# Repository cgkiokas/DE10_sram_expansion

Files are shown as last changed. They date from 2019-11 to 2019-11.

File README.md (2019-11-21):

# DE10 SRAM expansion board 
An SRAM expansion board for terasic DE-10 Nano board, with additional flight controller sensors.
Developed to accompany a DE-10 Nano board as a drone flight controller, using [T-CREST's Patmos](https://github.com/t-crest/patmos) processor. 

## Features
* 1Mx32bit SRAM
* 2 x 6-axis IMUs
* Magnetometer
* Barometer
* FTDI for UART output
* 7 GPIO Pins
  
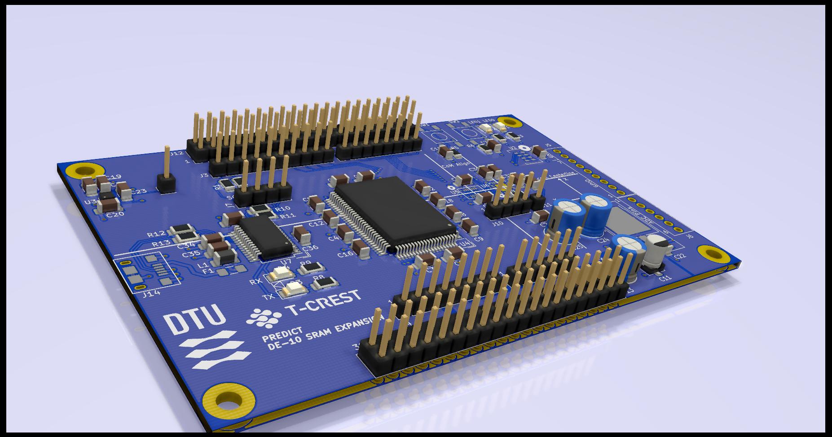
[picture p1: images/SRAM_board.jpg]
Title


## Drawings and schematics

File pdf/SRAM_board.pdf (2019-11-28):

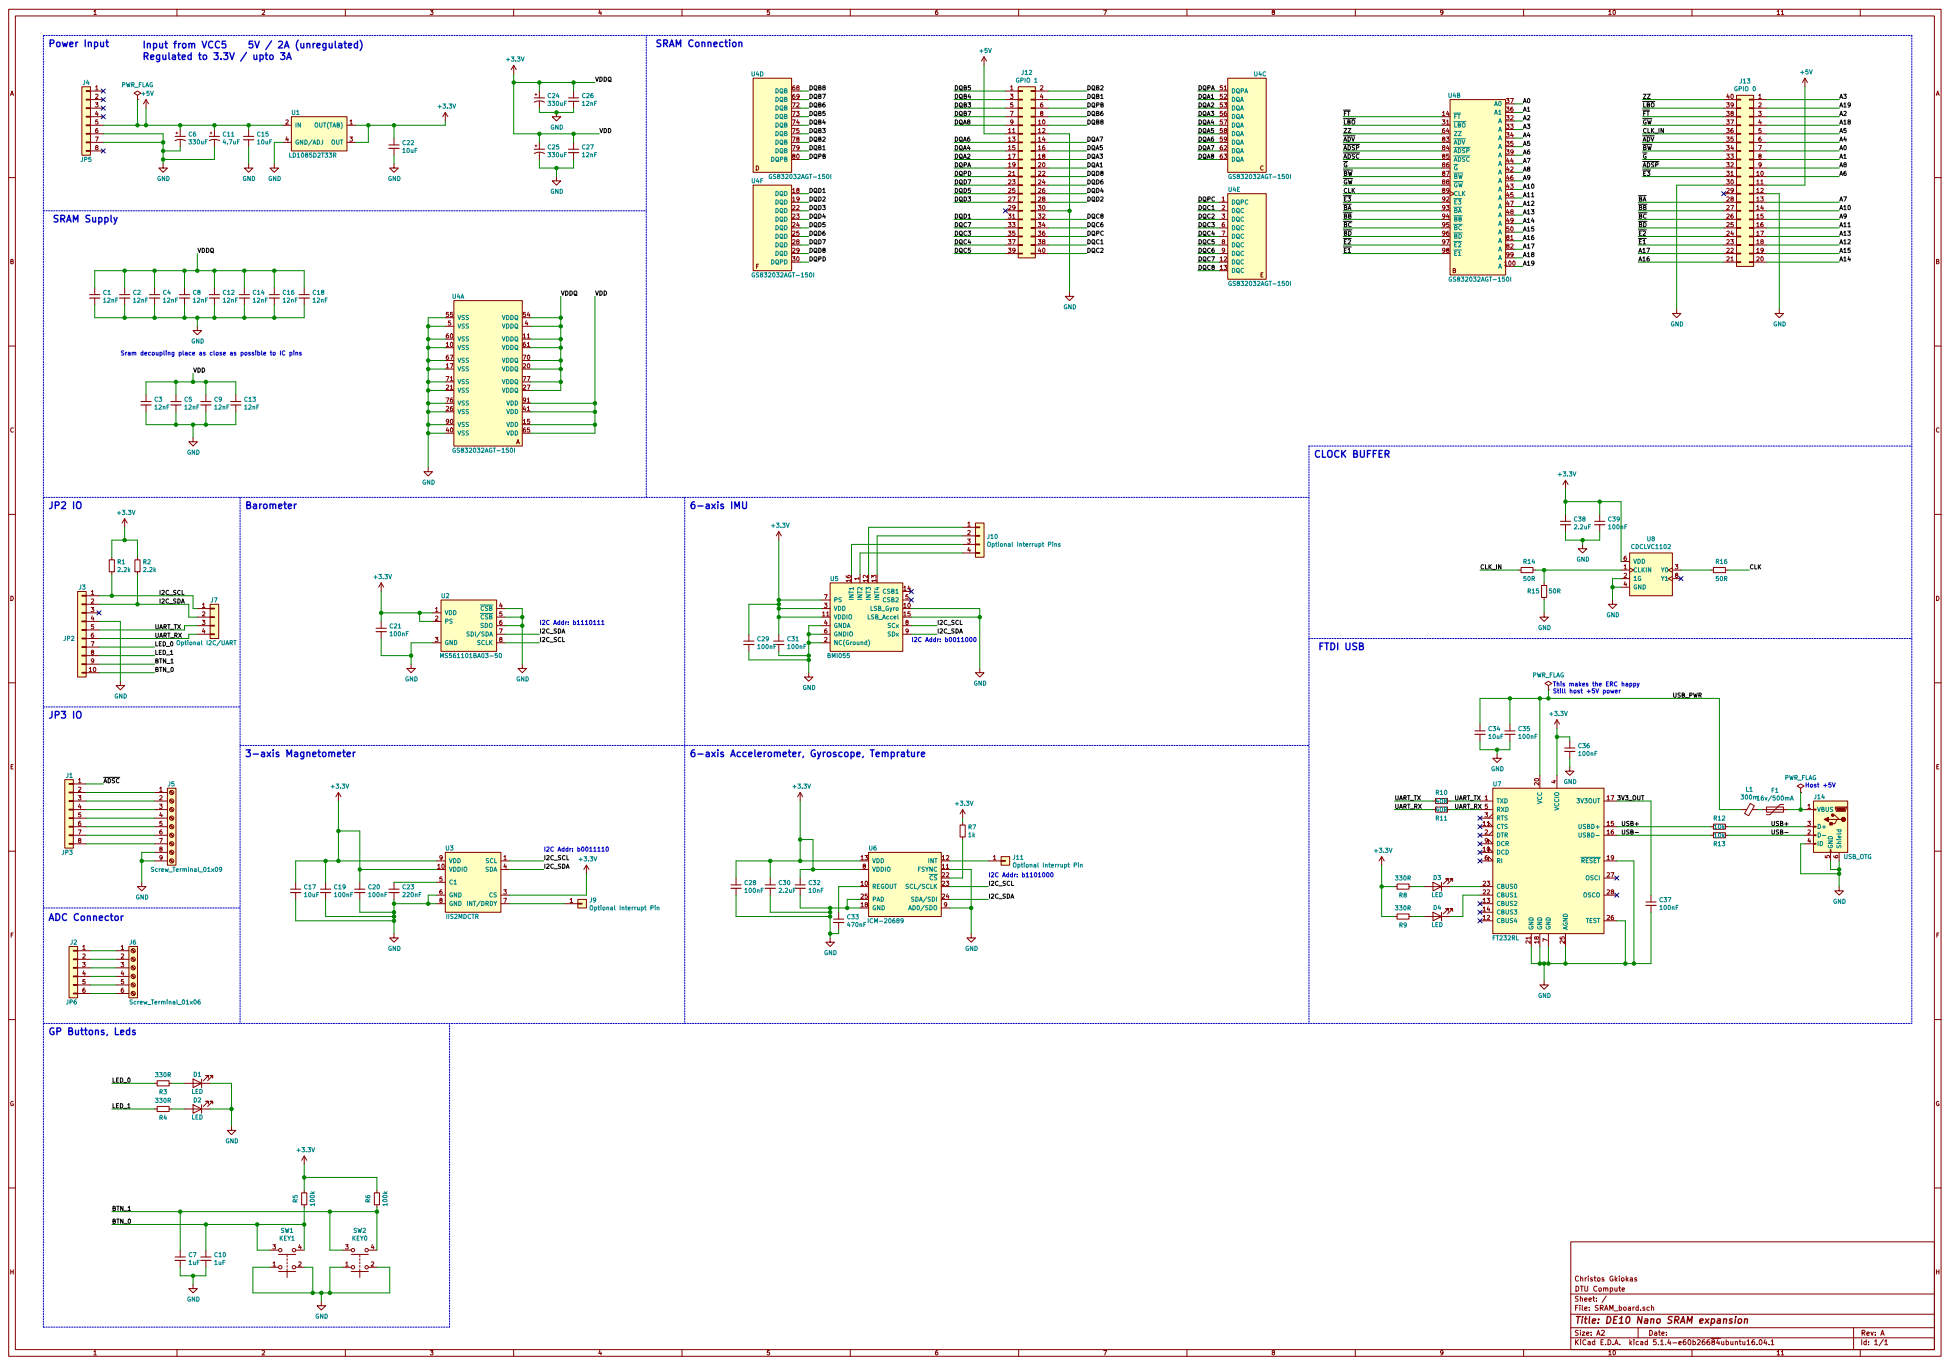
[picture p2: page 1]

JP2 IO +3.3V | LD1085D2T33R R6 100k +3.3V C10 Barometer +3.3V | 6-axis IMU | GND

Sram decoupling place as close as possible to IC pins

File: SRAM_board.sch Sheet: / DTU Compute Christos Gkiokas

Id: 1/1 Title: DE10 Nano SRAM expansion

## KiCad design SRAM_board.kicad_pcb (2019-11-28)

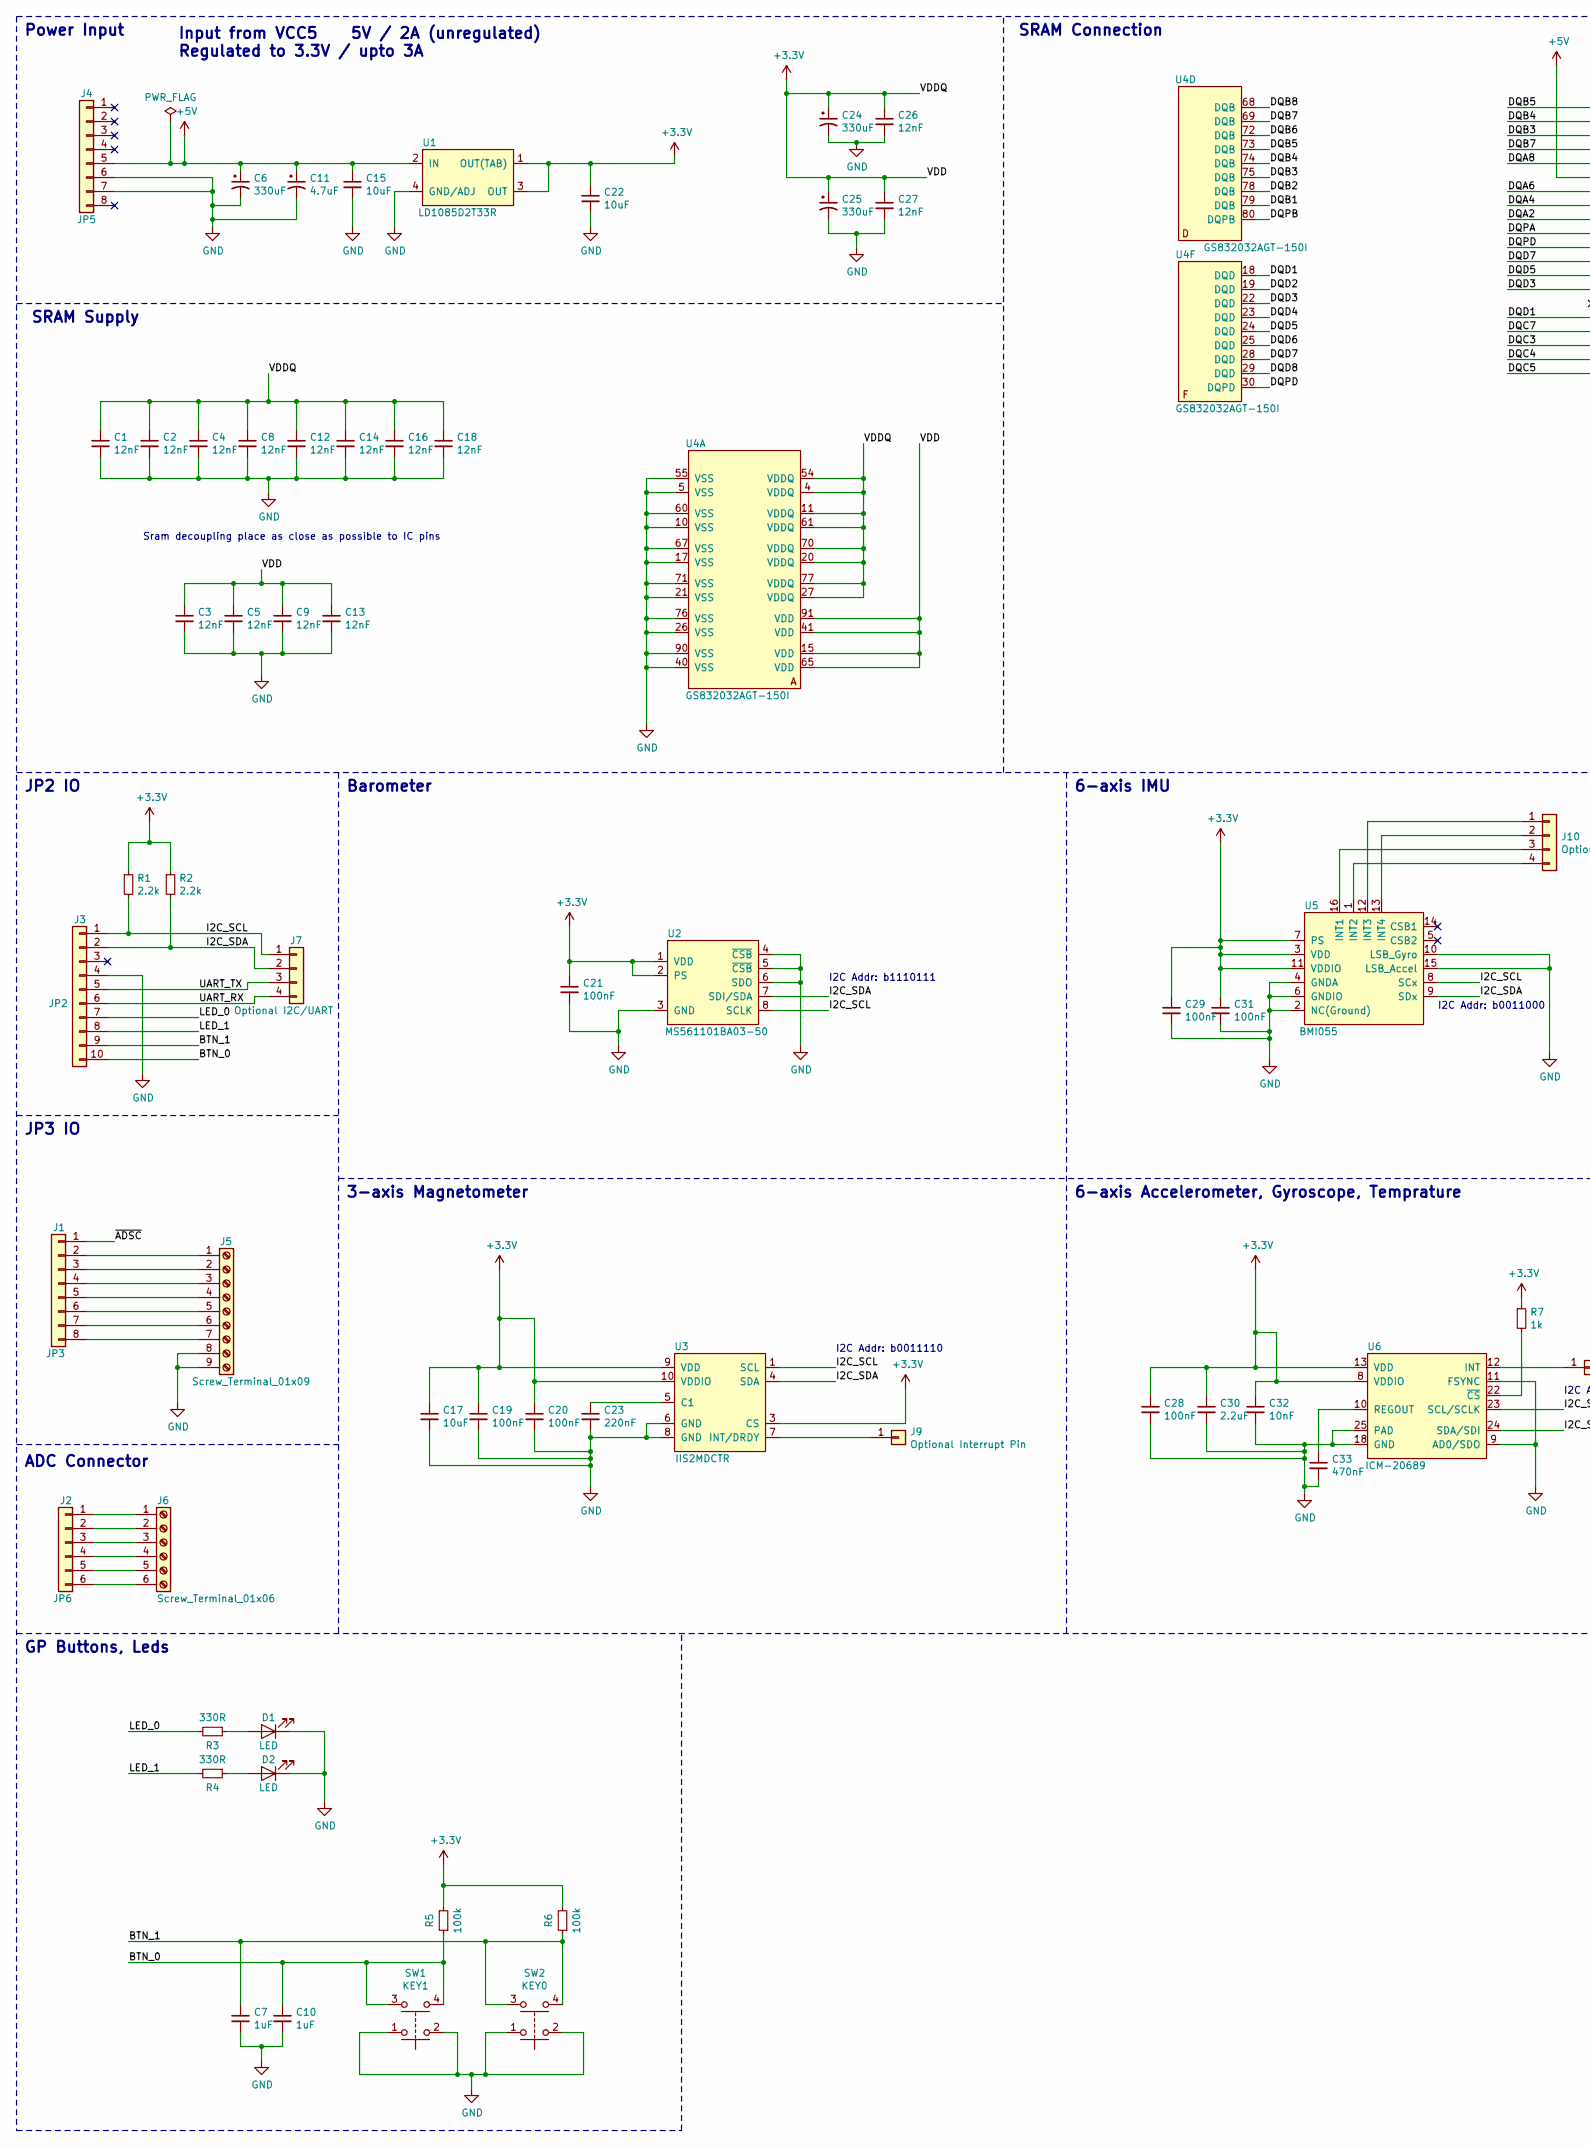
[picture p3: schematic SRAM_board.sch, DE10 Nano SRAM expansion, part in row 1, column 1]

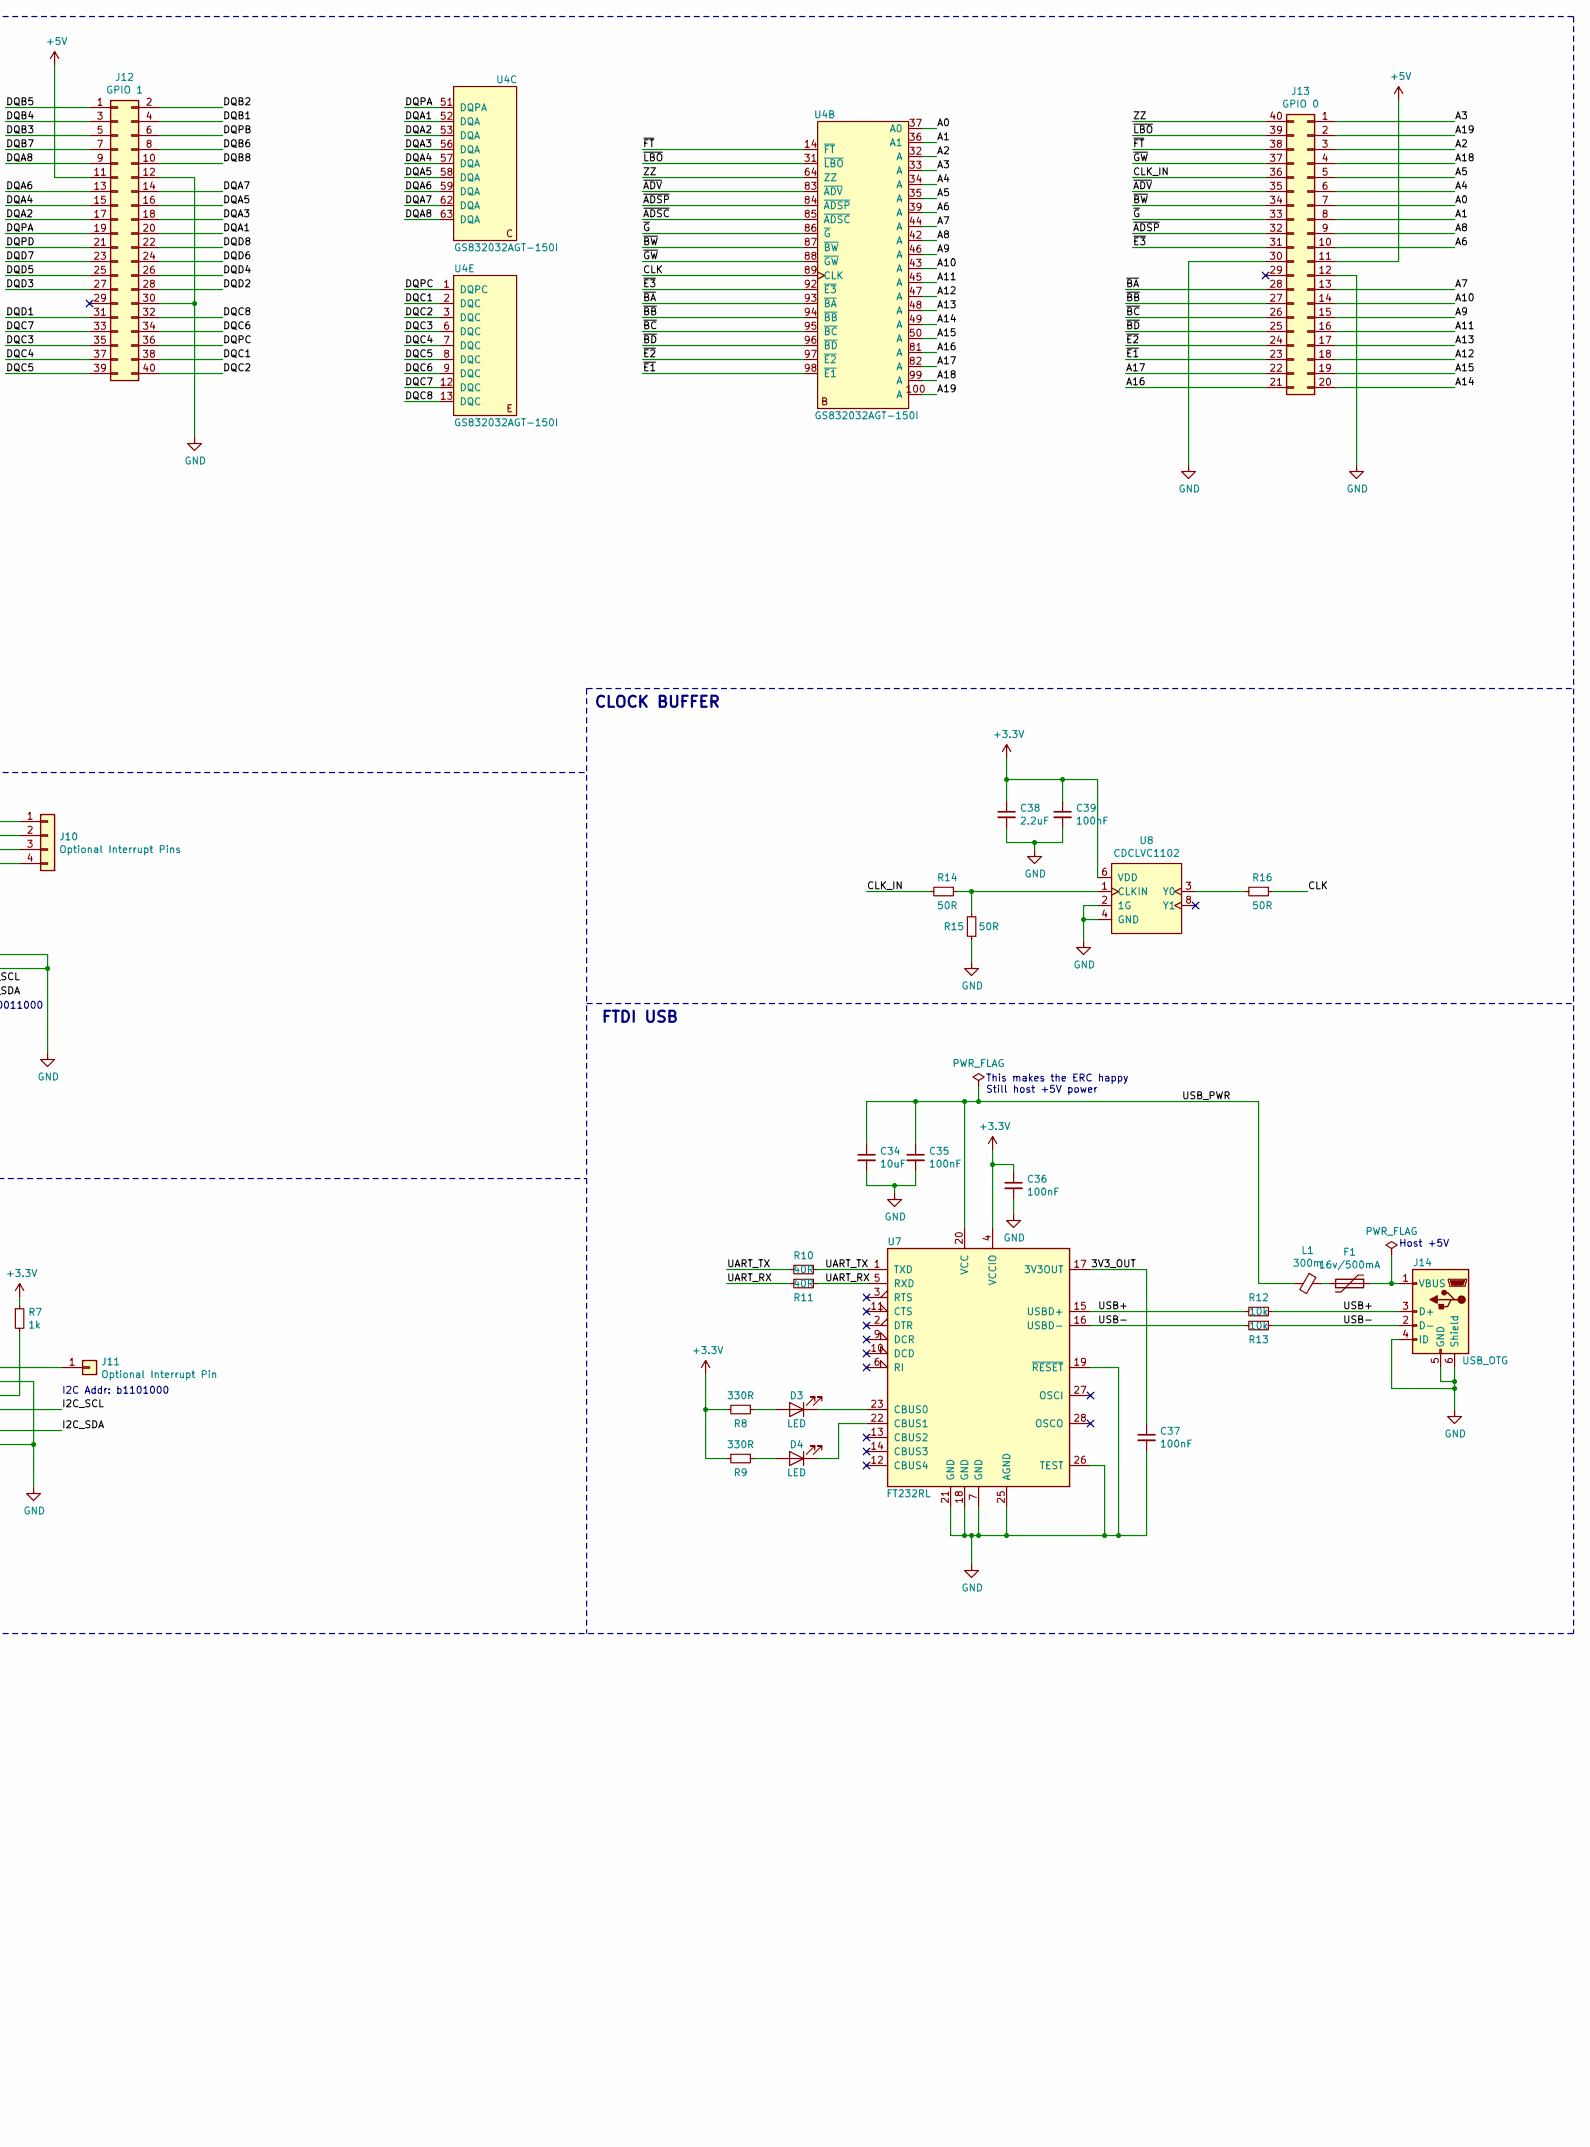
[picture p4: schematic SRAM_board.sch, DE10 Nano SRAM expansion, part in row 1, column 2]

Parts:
C1, C2, C3, C4, C5, C8, C9, C12, C13, C14, C16, C18, C26, C27: 12nF; C_1206_3216Metric_Pad1.42x1.75mm_HandSolder
C6, C24, C25: 330uF; CP_Radial_D6.3mm_P2.50mm
C7, C10: 1uF; C_1206_3216Metric_Pad1.42x1.75mm_HandSolder
C11: 4.7uF; CP_Elec_4x5.8
C15, C17, C22, C34: 10uF; C_1206_3216Metric_Pad1.42x1.75mm_HandSolder
C19, C20, C21, C28, C29, C31, C35, C36, C37, C39: 100nF; C_1206_3216Metric_Pad1.42x1.75mm_HandSolder
C23: 220nF; C_1206_3216Metric_Pad1.42x1.75mm_HandSolder
C30, C38: 2.2uF; C_1206_3216Metric_Pad1.42x1.75mm_HandSolder
C32: 10nF; C_1206_3216Metric_Pad1.42x1.75mm_HandSolder
C33: 470nF; C_1206_3216Metric_Pad1.42x1.75mm_HandSolder
D1, D2, D3, D4: LED; LED_1206_3216Metric_Pad1.42x1.75mm_HandSolder
F1: 16v/500mA; Fuse_1206_3216Metric_Pad1.42x1.75mm_HandSolder
J1: JP3; PinHeader_1x08_P2.54mm_Vertical
J2: JP6; PinHeader_1x06_P2.54mm_Vertical
J3: JP2; PinHeader_1x10_P2.54mm_Vertical
J4: JP5; PinHeader_1x08_P2.54mm_Vertical
J5: Screw_Terminal_01x09; Screw_Terminal_1x09_2.54'_pitch
J6: Screw_Terminal_01x06; Screw_Terminal_1x06_2.54'_pitch
J7: Optional I2C/UART; PinHeader_1x04_P2.54mm_Vertical
J9, J11: Optional Interrupt Pin; PinHeader_1x01_P2.54mm_Vertical
J10: Optional Interrupt Pins; PinHeader_1x04_P2.54mm_Vertical
J12: GPIO 1; PinHeader_2x20_P2.54mm_Vertical
J13: GPIO 0; PinHeader_2x20_P2.54mm_Vertical
J14: USB_OTG; FCI_10118193_0001LF
L1: 300m; L_1206_3216Metric_Pad1.42x1.75mm_HandSolder
R1, R2: 2.2k; R_1206_3216Metric_Pad1.42x1.75mm_HandSolder
R3, R4, R8, R9: 330R; R_1206_3216Metric_Pad1.42x1.75mm_HandSolder
R5, R6: 100k; R_1206_3216Metric_Pad1.42x1.75mm_HandSolder
R7: 1k; R_1206_3216Metric_Pad1.42x1.75mm_HandSolder
R10, R11: 40R; R_1206_3216Metric_Pad1.42x1.75mm_HandSolder
R12, R13: 10k; R_1206_3216Metric_Pad1.42x1.75mm_HandSolder
R14, R15, R16: 50R; R_1206_3216Metric_Pad1.42x1.75mm_HandSolder
SW1: KEY1; LL3301NF065QG
SW2: KEY0; LL3301NF065QG
U1: LD1085D2T33R
U2: MS561101BA03-50
U3: IIS2MDCTR; LGA-12_2x2mm_P0.5mm
U4: GS832032AGT-150I; PQFP-100_14x20mm_P0.65mm
U5: BMI055
U6: ICM-20689
U7: FT232RL; SSOP-28_5.3x10.2mm_P0.65mm
U8: CDCLVC1102; SOIC-8

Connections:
+3V3: C1.1, C2.1, C3.1, C4.1, C5.1, C8.1, C9.1, C12.1, C13.1, C14.1, C16.1, C17.1, C18.1, C19.1, C20.1, C21.1, C22.1, C24.1, C25.1, C26.1, C27.1, C28.1, C29.1, C30.1, C31.1, C32.1, C36.1, C38.1, C39.1, R1.1, R2.1, R5.2, R6.2, R7.1, R8.2, R9.2, U1.1 (OUT(TAB)), U1.3 (OUT), U2.1 (VDD), U2.2 (PS), U3.3 (CS), U3.9 (VDD), U3.10 (VDDIO), U4.4 (VDDQ), U4.11 (VDDQ), U4.15 (VDD), U4.20 (VDDQ), U4.27 (VDDQ), U4.41 (VDD), U4.54 (VDDQ), U4.61 (VDDQ), U4.65 (VDD), U4.70 (VDDQ), U4.77 (VDDQ), U4.91 (VDD), U5.3 (VDD), U5.7 (PS), U5.11 (VDDIO), U6.8 (VDDIO), U6.13 (VDD), U7.4 (VCCIO), U8.6 (VDD)
+5V: C6.1, C11.1, C15.1, J4.5, J12.11, J13.11, U1.2 (IN)
/3V3_OUT: C37.1, U7.17 (3V3OUT)
/A0: J13.7, U4.37 (A0)
/A1: J13.8, U4.36 (A1)
/A2: J13.3, U4.32 (A)
/A3: J13.1, U4.33 (A)
/A4: J13.6, U4.34 (A)
/A5: J13.5, U4.35 (A)
/A6: J13.10, U4.39 (A)
/A7: J13.13, U4.44 (A)
/A8: J13.9, U4.42 (A)
/A9: J13.15, U4.46 (A)
/A10: J13.14, U4.43 (A)
/A11: J13.16, U4.45 (A)
/A12: J13.18, U4.47 (A)
/A13: J13.17, U4.48 (A)
/A14: J13.20, U4.49 (A)
/A15: J13.19, U4.50 (A)
/A16: J13.21, U4.81 (A)
/A17: J13.22, U4.82 (A)
/A18: J13.4, U4.99 (A)
/A19: J13.2, U4.100 (A)
/BTN_0: C10.1, J3.10, R5.1, SW1.3, SW1.4
/BTN_1: C7.1, J3.9, R6.1, SW2.3, SW2.4
/CLK: R16.1, U4.89 (CLK)
/CLK_IN: J13.36, R14.2
/DQA1: J12.20, U4.52 (DQA)
/DQA2: J12.17, U4.53 (DQA)
/DQA3: J12.18, U4.56 (DQA)
/DQA4: J12.15, U4.57 (DQA)
/DQA5: J12.16, U4.58 (DQA)
/DQA6: J12.13, U4.59 (DQA)
/DQA7: J12.14, U4.62 (DQA)
/DQA8: J12.9, U4.63 (DQA)
/DQB1: J12.4, U4.79 (DQB)
/DQB2: J12.2, U4.78 (DQB)
/DQB3: J12.5, U4.75 (DQB)
/DQB4: J12.3, U4.74 (DQB)
/DQB5: J12.1, U4.73 (DQB)
/DQB6: J12.8, U4.72 (DQB)
/DQB7: J12.7, U4.69 (DQB)
/DQB8: J12.10, U4.68 (DQB)
/DQC1: J12.38, U4.2 (DQC)
/DQC2: J12.40, U4.3 (DQC)
/DQC3: J12.35, U4.6 (DQC)
/DQC4: J12.37, U4.7 (DQC)
/DQC5: J12.39, U4.8 (DQC)
/DQC6: J12.34, U4.9 (DQC)
/DQC7: J12.33, U4.12 (DQC)
/DQC8: J12.32, U4.13 (DQC)
/DQD1: J12.31, U4.18 (DQD)
/DQD2: J12.28, U4.19 (DQD)
/DQD3: J12.27, U4.22 (DQD)
/DQD4: J12.26, U4.23 (DQD)
/DQD5: J12.25, U4.24 (DQD)
/DQD6: J12.24, U4.25 (DQD)
/DQD7: J12.23, U4.28 (DQD)
/DQD8: J12.22, U4.29 (DQD)
/DQPA: J12.19, U4.51 (DQPA)
/DQPB: J12.6, U4.80 (DQPB)
/DQPC: J12.36, U4.1 (DQPC)
/DQPD: J12.21, U4.30 (DQPD)
/I2C_SCL: J3.1, J7.1, R1.2, U2.8 (SCLK), U3.1 (SCL), U5.8 (SCx), U6.23 (SCL/SCLK)
/I2C_SDA: J3.2, J7.2, R2.2, U2.7 (SDI/SDA), U3.4 (SDA), U5.9 (SDx), U6.24 (SDA/SDI)
/LED_0: J3.7, R3.2
/LED_1: J3.8, R4.2
/UART_RX: J3.6, J7.4, R11.1, R11.2, U7.5 (RXD)
/UART_TX: J3.5, J7.3, R10.1, R10.2, U7.1 (TXD)
/USB+: J14.3 (D+), R12.1, R12.2, U7.15 (USBD+)
/USB-: J14.2 (D-), R13.1, R13.2, U7.16 (USBD-)
/USB_PWR: C34.1, C35.1, L1.2, U7.20 (VCC)
/ZZ: J13.40, U4.64 (ZZ)
/~ADSC: J1.1, U4.85 (~ADSC)
/~ADSP: J13.32, U4.84 (~ADSP)
/~ADV: J13.35, U4.83 (~ADV)
/~BA: J13.28, U4.93 (~BA)
/~BB: J13.27, U4.94 (~BB)
/~BC: J13.26, U4.95 (~BC)
/~BD: J13.25, U4.96 (~BD)
/~BW: J13.34, U4.87 (~BW)
/~E1: J13.23, U4.98 (~E1)
/~E2: J13.24, U4.97 (~E2)
/~E3: J13.31, U4.92 (~E3)
/~FT: J13.38, U4.14 (~FT)
/~G: J13.33, U4.86 (~G)
/~GW: J13.37, U4.88 (~GW)
/~LBO: J13.39, U4.31 (~LBO)
GND: C1.2, C2.2, C3.2, C4.2, C5.2, C6.2, C7.2, C8.2, C9.2, C10.2, C11.2, C12.2, C13.2, C14.2, C15.2, C16.2, C17.2, C18.2, C19.2, C20.2, C21.2, C22.2, C23.2, C24.2, C25.2, C26.2, C27.2, C28.2, C29.2, C30.2, C31.2, C32.2, C33.2, C34.2, C35.2, C36.2, C37.2, C38.2, C39.2, D1.1 (K), D2.1 (K), J3.4, J4.6, J4.7, J5.8, J5.9, J12.12, J12.30, J13.12, J13.30, J14.4 (ID), J14.5 (GND), J14.6 (Shield), R15.1, SW1.1, SW1.2, SW2.1, SW2.2, U1.4 (GND/ADJ), U2.3 (GND), U2.4 (~CSB), U2.5 (~CSB), U2.6 (SDO), U3.6 (GND), U3.8 (GND), U4.5 (VSS), U4.10 (VSS), U4.17 (VSS), U4.21 (VSS), U4.26 (VSS), U4.40 (VSS), U4.55 (VSS), U4.60 (VSS), U4.67 (VSS), U4.71 (VSS), U4.76 (VSS), U4.90 (VSS), U5.2 (NC(Ground)), U5.4 (GNDA), U5.6 (GNDIO), U5.10 (LSB_Gyro), U5.15 (LSB_Accel), U6.9 (AD0/SDO), U6.11 (FSYNC), U6.18 (GND), U6.25 (PAD), U7.7 (GND), U7.18 (GND), U7.19 (~RESET~), U7.21 (GND), U7.25 (AGND), U7.26 (TEST), U8.2 (1G), U8.4 (GND)
unnamed: C23.1, U3.5 (C1)
unnamed: C33.1, U6.10 (REGOUT)
unnamed: D1.2 (A), R3.1
unnamed: D2.2 (A), R4.1
unnamed: D3.1 (K), U7.23 (CBUS0)
unnamed: D3.2 (A), R8.1
unnamed: D4.1 (K), U7.22 (CBUS1)
unnamed: D4.2 (A), R9.1
unnamed: F1.1, J14.1 (VBUS)
unnamed: F1.2, L1.1
unnamed: J1.2, J5.1
unnamed: J1.3, J5.2
unnamed: J1.4, J5.3
unnamed: J1.5, J5.4
unnamed: J1.6, J5.5
unnamed: J1.7, J5.6
unnamed: J1.8, J5.7
unnamed: J2.1, J6.1
unnamed: J2.2, J6.2
unnamed: J2.3, J6.3
unnamed: J2.4, J6.4
unnamed: J2.5, J6.5
unnamed: J2.6, J6.6
unnamed: J9.1, U3.7 (INT/DRDY)
unnamed: J10.1, U5.12 (INT3)
unnamed: J10.2, U5.13 (INT4)
unnamed: J10.3, U5.16 (INT1)
unnamed: J10.4, U5.1 (INT2)
unnamed: J11.1, U6.12 (INT)
unnamed: R7.2, U6.22 (~CS)
unnamed: R14.1, R15.2, U8.1 (CLKIN)
unnamed: R16.2, U8.3 (Y0)

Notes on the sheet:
Input from VCC5 5V / 2A (unregulated) Regulated to 3.3V / upto 3A
I2C Addr: b1101000
I2C Addr: b0011110
I2C Addr: b0011000
I2C Addr: b1110111
Power Input
SRAM Supply
JP2 IO
SRAM Connection
Barometer
6-axis IMU
3-axis Magnetometer
6-axis Accelerometer, Gyroscope, Temprature
FTDI USB
ADC Connector
JP3 IO
GP Buttons, Leds
Host +5V
This makes the ERC happy Still host +5V power
Sram decoupling place as close as possible to IC pins
CLOCK BUFFER

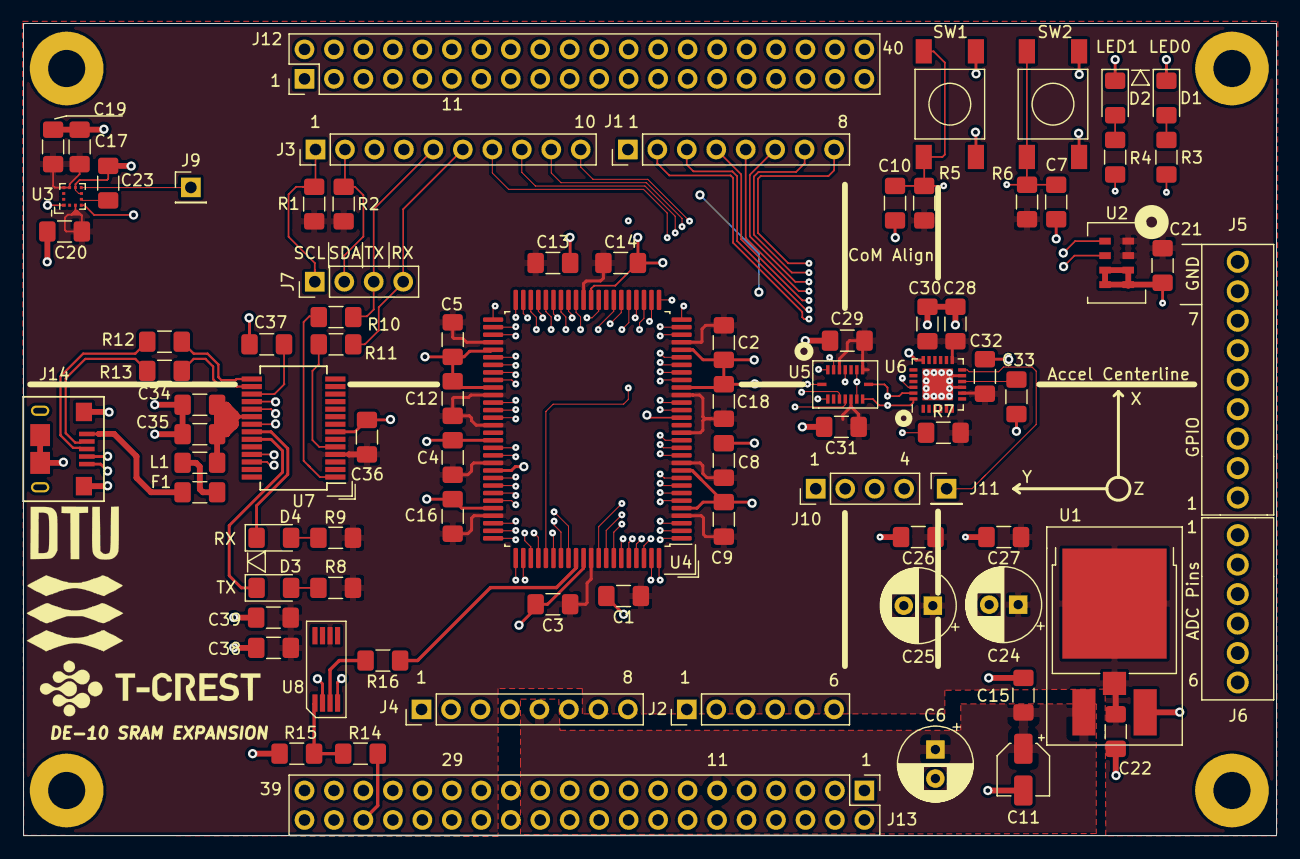
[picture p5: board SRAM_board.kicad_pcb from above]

Board: 4 copper layers, 108.0 x 70.0 mm, 84 parts (0 on the bottom side), 121 nets.

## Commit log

2019-11-22 celanup, I2C improvment, SRAM clock buffer
    [SRAM_board-B_Cu.gbr, SRAM_board-B_Mask.gbr, SRAM_board-B_Paste.gbr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]
2019-11-28 switch sram clock pin
    [SRAM_board-B_Cu.gbr, SRAM_board-B_Mask.gbr, SRAM_board-B_Paste.gbr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]
